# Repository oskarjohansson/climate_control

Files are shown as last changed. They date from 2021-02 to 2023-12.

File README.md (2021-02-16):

# Boot Climate Control
> Created by Benjamin Lundgren & Oskar Johansson

Based on [Ski boots hearing system](https://hackaday.io/project/163132-ski-boots-heating-system). 

## Goals 
> The goal of the Boot Climate Control (BCC)
```
- Never ever freeze in the boots
- Warm for ~8h
```

## Directories 
```
climate_control
├── document        # Generic document folder
│   ├── datasheet   # Datasheet for hardware components  
├── hardware        
│   ├── cad         # 3D models
│   │   └── stl     # 3D print files
│   ├── pcb         # Schematic, layout and production files
│   │   └── gerber  # Production files
│   │   └── library # Library for project
├── img             
└── software        # Firmware files
```

## Usage
> Description about how to use the BCC 

## License
> This template is created with MIT license.
>
> ](http://badges.mit-license.org)

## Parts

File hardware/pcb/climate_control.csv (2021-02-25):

Id | Designator | Package | Quantity | Designation | Supplier and ref
1 | J1 | JST_XH_B4B-XH-A_1x04_P2.50mm_Vertical | 1 | Switch |  | CASE
2 | U3 | TQFP-32_7x7mm_P0.8mm | 1 | ATmega328PB-AU |  | Benjamin
3 | C1,C4,C7,C8,C10 | C_0603_1608Metric | 5 | 10uF | C344022 | LCSC
4 | U1 | SOP8-EPAD | 1 | TP4056 | C725790 | LCSC
5 | U2 | SOP8-EPAD | 1 | XB8089A | C669690 | LCSC
6 | U4 | Texas_S-PVSON-N10_ThermalVias | 1 | TPS61230DRC | C139626 | LCSC
7 | D1 | D_0603_1608Metric | 1 | CHRG | C84269 | LCSC
8 | Q2 | SOT-23 | 1 | NTR3C21NZ | C344010 | LCSC
9 | J2 | JST_XH_B2B-XH-A_1x02_P2.50mm_Vertical | 1 | BatteryIn
10 | J4 | JST_XH_B2B-XH-A_1x02_P2.50mm_Vertical | 1 | HeatElement
11 | R1,R4 | R_0402_1005Metric | 2 | x
12 | R2,R14 | R_0402_1005Metric | 2 | 10k
13 | R9,R13 | R_0402_1005Metric | 2 | 5.1k
14 | R11 | R_0402_1005Metric | 1 | 2.4k
15 | R12 | R_0402_1005Metric | 1 | 100R
16 | R15,R3 | R_0402_1005Metric | 2 | 100k
17 | R17,R18 | R_0402_1005Metric | 2 | R_Small
18 | C3,C6,C11 | C_0402_1005Metric | 3 | 100nF
19 | C5 | C_0402_1005Metric | 1 | 1uF
20 | C9 | C_0402_1005Metric | 1 | 18nF
21 | J3 | HRO_TYPE-C-31-M-12 | 1 | USB_C | C165948 | LCSC
22 | J5 | PinHeader_2x03_P2.54mm_Vertical | 1 | ICSP
23 | L1 | Inductor_0530 | 1 | 1uH | C169353 | LCSC
24 | R5 | R_0402_1005Metric | 1 | 30k

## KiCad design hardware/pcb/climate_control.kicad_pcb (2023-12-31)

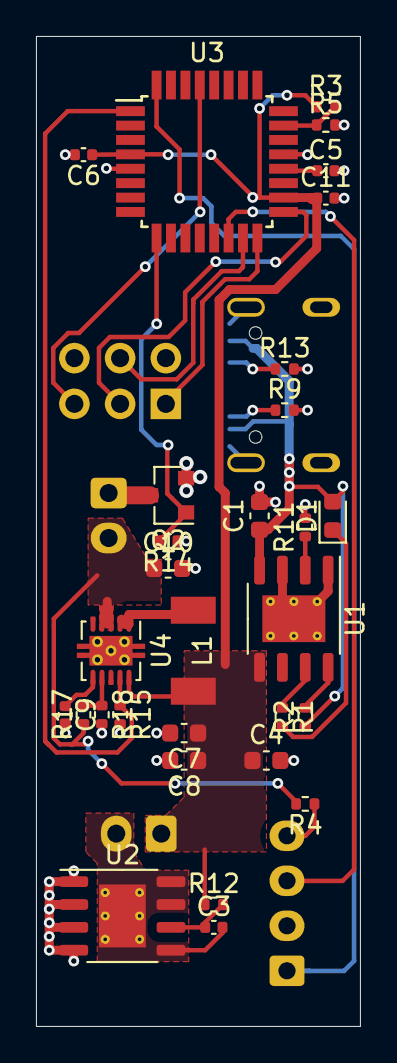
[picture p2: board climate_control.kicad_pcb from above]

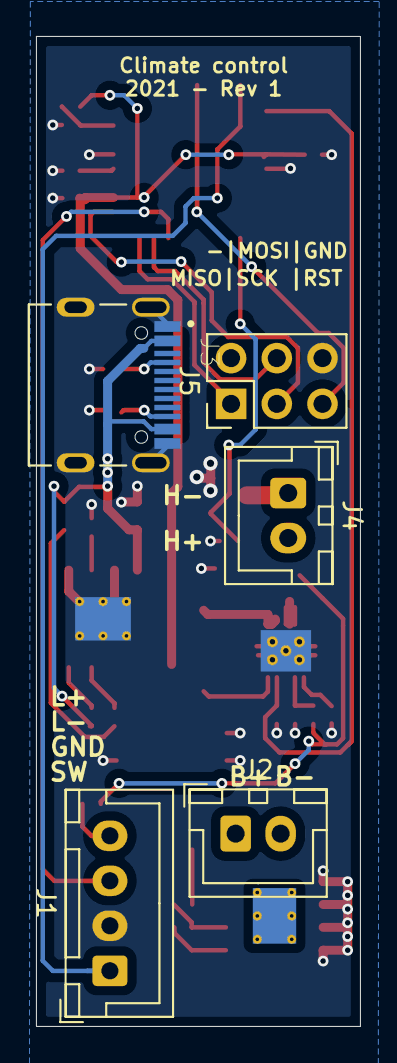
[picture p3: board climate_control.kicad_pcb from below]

Board: 2 copper layers, 18.0 x 55.0 mm, 35 parts (5 on the bottom side), 27 nets.

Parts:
C1, C4, C7, C8, C10: 10uF; C_0603_1608Metric
C3, C6, C11: 100nF; C_0402_1005Metric
C5: 1uF; C_0402_1005Metric
C9: 18nF; C_0402_1005Metric
D1: CHRG; D_0603_1608Metric
J1: Switch; JST_XH_B4B-XH-A_1x04_P2.50mm_Vertical
J2: BatteryIn; JST_XH_B2B-XH-A_1x02_P2.50mm_Vertical
J3: USB_C; HRO_TYPE-C-31-M-12
J4: HeatElement; JST_XH_B2B-XH-A_1x02_P2.50mm_Vertical
J5: ICSP; PinHeader_2x03_P2.54mm_Vertical
L1: 1uH; Inductor_0530
Q2: NTR3C21NZ; SOT-23
R1, R4: x; R_0402_1005Metric
R2, R14: 10k; R_0402_1005Metric
R3, R15: 100k; R_0402_1005Metric
R5: 30k; R_0402_1005Metric
R9, R13: 5.1k; R_0402_1005Metric
R11: 2.4k; R_0402_1005Metric
R12: 100R; R_0402_1005Metric
R17, R18: R_Small; R_0402_1005Metric
U1: TP4056; SOP8-EPAD
U2: XB8089A; SOP8-EPAD
U3: ATmega328PB-AU; TQFP-32_7x7mm_P0.8mm
U4: TPS61230DRC; Texas_S-PVSON-N10_ThermalVias

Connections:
+5V: C1.1, D1.2, J3.A4B9, J3.B4A9, R2.1, U1.4
+BATT: C4.1, C6.1, C7.1, C8.1, C11.1, J2.1, L1.1, R3.1, R12.1, U1.5, U3.4, U3.18, U4.10
+VSW: C10.1, J4.2, R4.2, R17.1, U4.3, U4.4
-BATT: C3.2, J2.2, U2.5, U2.7, U2.8, U2.9
BAT: R3.2, R5.1, U3.23
BOOST_EN: R15.1, U3.1, U4.9
GND: C1.2, C4.2, C5.2, C6.2, C7.2, C8.2, C9.2, C10.2, C11.2, J1.2, J3.A1B12, J3.B1A12, J3.S1, J5.6, Q2.2, R5.2, R9.2, R11.2, R13.2, R14.1, R15.2, R18.2, U1.1, U1.3, U1.9, U2.1, U2.2, U2.3, U2.4, U3.5, U3.21, U4.11
HEATER_PWM: Q2.1, R14.2, U3.9
LED: J1.3, U3.14
MISO: J5.1, U3.16
MOSI: J5.4, U3.15
unnamed: C3.1, R12.2, U2.6
unnamed: C5.1, U3.20
unnamed: C9.1, U4.6
unnamed: D1.1, R1.2
unnamed: J1.4, R4.1
unnamed: J3.A5, R13.1
unnamed: J3.B5, R9.1
unnamed: J4.1, Q2.3
unnamed: L1.2, U4.1, U4.2
unnamed: R1.1, U1.7
unnamed: R2.2, U1.8
unnamed: R11.1, U1.2
unnamed: R17.2, R18.1, U4.7
SCK: J5.3, U3.17
SWITCH: J1.1, U3.32
~RST: J5.5, U3.29

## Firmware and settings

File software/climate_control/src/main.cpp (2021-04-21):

#include <Arduino.h>
#include <utils.h>
#include <button.h>
#include <heater.h>
#include <constants.h>

/*
DONE: Verify debouncing and click pattern detection
DONE: Verify Led output
DONE: Verify boost circuit working

TODO: Verify getSoc()
TODO: Verify sleep function (measure current draw)
TODO: Verify heater function
*/
Button switchButton(switchPin);
Heater heater(heaterPwmPin, boostEnablePin, ledPin);

// For battery soc led
uint8_t queueIndex = 0;
unsigned long socLastCycle = 5000;

void setup()
{
  Serial.begin(9600);
  //Serial.println("Hello World!");
  pinMode(ledPin,INPUT);
  flash(ledPin, 3, 250, 250);
  pinMode(boostEnablePin,OUTPUT);
  digitalWrite(boostEnablePin,HIGH);
  analogReference(INTERNAL1V1);
}

void loop()
{
  unsigned long now = millis();
  // Read battery status
  uint8_t Soc = getSoc();
  if (Soc)
  {
    // Check if button is pressed
    int click = switchButton.poll();
    switch (click)
    {
      case clickTypes::singleClick:
        //Serial.println("Single click detected!");
        socLastCycle = now + socLedCycle;
        if (heater.isActive())
          heater.increment();
        break;
      case clickTypes::doubleClick:
        //Serial.println("Double click detected!");
        socLastCycle = now + socLedCycle;
        if (heater.isActive())
          heater.decrement();
        break;
      case clickTypes::tripleClick:
      { // Get battery status
        //Serial.println("Triple click detected!");
        socLastCycle = now + socLedCycle;
        //heater.pause();
        //delay(10);
        //uint8_t soc = getSoc();
        //flash(ledPin, soc+1, 500, 250);
        //heater.resume();
        break;
      }
      case clickTypes::longClick:
        if (heater.isActive())
        {
          //Serial.println("Turning off heater!");
          heater.off();
        }
        else
        {
          //Serial.println("Turning on heater!");
          heater.on();
        }
        break;
      
    }
    // If neither heater active nor switchbutton active
    if (!(switchButton.isActive() || heater.isActive()))
    {
      //Serial.println("Inactive, going to sleep!");
      delay(25);
      goToSleep();
    }

    // Blink battery level led
    else if((now>socLastCycle))
    {
      Serial.print(Soc); Serial.print(" "); Serial.println(analogRead(batSensePin));
      uint8_t ledMode = socLedPattern[Soc-1][queueIndex];
      if(ledMode) 
      {        
        pinMode(ledPin, OUTPUT);
        digitalWrite(ledPin, LOW);
      }
      else 
      {
        pinMode(ledPin, INPUT);
      }

      queueIndex = (queueIndex + 1) % (sizeof(socLedPattern[Soc])+1);
      // If queueIndex is zero, wait another 5s
      if(queueIndex<1){
        socLastCycle = now + socLedCycle;
        pinMode(ledPin, OUTPUT);
        digitalWrite(ledPin, LOW);
      }
      else 
      {
        socLastCycle = now + socLedTimestep;
      }
    }





  }
  else
  {
    delay(25);
    //disable heater
    heater.off();
    //disable led
    pinMode(ledPin, INPUT);
    // Sleep
    goToSleep();
  }
}

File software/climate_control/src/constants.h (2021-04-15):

#ifndef __CONSTANTS__
#define __CONSTANTS__
const int switchPin = 2;       //PD2
const int switchInterrupt = 0; //PD2

const int boostEnablePin = 3; //PD3
const int boostMosPin = 4;    //PD4
const int heaterPwmPin = 5;   //PD5
const int usbDetectPin = 16;  //PC2
const int ledPin = 10;        //PB2
const int batSensePin = A0;

const int debouncingTime = 50;
const int groupClickInterval = 300; 
const int longClickDuration = 1000;
const int inactiveTime = 5000;

const unsigned long socLedTimestep = 400;   // Timestep
const unsigned long socLedCycle = 5000;     // How often the soc should cycle
const uint8_t socLedPattern[3][5] = {{0,1,1,1,1},{0,1,0,1,1},{0,1,0,1,0}}; // The pattern for the three battery levels

const float voltPerInc = 0.0062; // Magic number ;-) 1.1 * ((100 + 30) / 30) / 1024; // internal_ref * voltage_division⁽⁻¹⁾ / resolution
//const int underVoltThreshold = 447; //2.8 / voltPerInc;
const int underVoltThreshold = 635; //2.8 / voltPerInc;

const int batteryReads = 10;
const int batSocVoltageLevels = 3;
//const unsigned int batSocVoltage[] = {underVoltThreshold, 535, 624};
const int batSocVoltage[] = {underVoltThreshold, 760, 830};
                                      /*{(unsigned int)(3.48 / voltPerInc),  // ~20%
                                      (unsigned int)(3.60 / voltPerInc),  // ~40%
                                      (unsigned int)(3.71 / voltPerInc),  // ~60%
                                      (unsigned int)(3.90 / voltPerInc),  // ~80%
                                      (unsigned int)(4.15 / voltPerInc)}; // ~ 95%*/

enum clickTypes {
    noClick,
    singleClick,
    doubleClick,
    tripleClick,
    longClick
};

const int heaterStartLevel = 1;
const int heaterNumberOfLevels = 2;
const int heaterLevels[] = {100, 175, 255};

#endif

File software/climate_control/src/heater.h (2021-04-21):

#include <constants.h>

class Heater
{
    uint8_t currentLevel;
    bool active;


    uint8_t pwmPin;
    uint8_t enablePin;
    uint8_t ledPin;

    public:
    Heater(uint8_t pwmPin, uint8_t enablePin, uint8_t ledPin)
    {
        this->pwmPin = pwmPin;
        this->enablePin = enablePin;
        this->ledPin = ledPin;
        digitalWrite(pwmPin, LOW);
        digitalWrite(enablePin, LOW);

        currentLevel = 0;
        active = false;
    }
    
    void pause()
    {
        digitalWrite(pwmPin, LOW);
        digitalWrite(enablePin, LOW);
        active = false;
    }
    void resume()
    {
        analogWrite(pwmPin, heaterLevels[currentLevel]);
        digitalWrite(enablePin, HIGH);
        active = true;
    }
    void off()
    {
        digitalWrite(pwmPin, LOW);
        digitalWrite(enablePin, LOW);
        active = false;
        currentLevel = 0;
        pinMode(ledPin, INPUT);
    }
    void on()
    {
        currentLevel = heaterStartLevel;
        digitalWrite(enablePin, HIGH);
        analogWrite(pwmPin, heaterLevels[currentLevel]);
        pinMode(ledPin, OUTPUT);
        digitalWrite(ledPin, LOW);
        active = true;
    }

    void increment()
    {
        if (currentLevel < (heaterNumberOfLevels))
            currentLevel ++;
        active = true;
        digitalWrite(enablePin, HIGH);
        analogWrite(pwmPin, heaterLevels[currentLevel]);
        flash(ledPin, currentLevel+1, 200, 200);
        pinMode(ledPin, OUTPUT);
        digitalWrite(ledPin, LOW);
    }
    void decrement()
    {
        if (currentLevel > 0)
            currentLevel --;
        active = true;
        digitalWrite(enablePin, HIGH);
        analogWrite(pwmPin, heaterLevels[currentLevel]);
        flash(ledPin, currentLevel+1, 200, 200);
        pinMode(ledPin, OUTPUT);
        digitalWrite(ledPin, LOW);
    }
    bool isActive()
    {
        return active;
    }
};

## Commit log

2021-02-16 Added components to schematic and library
    Added Battery protection
    Added Boost charger
    Added USB Connector
    Added Boost module
2021-02-16 Correct title on battery charger.
    Wrote boost before, when it is a buck charger. Now corrected.
    [climate_control.sch]
2021-02-17 Added image of Arduino Pro Mini
2021-02-17 Added datasheet for BMS
2021-02-17 Added MCU and better control.
    MCU with all connection is added.
    Output to heater now has a mosfet to PWM to.
    LED Switch has a connection with mosfet to control LED.
    LED Switch has a LP filter for debounce purpose.
    [climate_control.sch]
2021-02-18 All components added to schematic and pcb.
    Footprints for all parts is done and only routing is left.
    [climate_control.sch]
2021-02-18 Removed resistor on TP4056.
    Updated on PCB the routing.
    [climate_control.kicad_pcb, climate_control.sch]
2021-02-18 First routing complete.
    The first routing is done, now it must be improved!
    [climate_control.kicad_pcb]
2021-02-18 Added comments on LED/Switch circuitry
    [climate_control.sch]
2021-02-20 Removed unnececary components
    [climate_control.kicad_pcb, climate_control.sch]
2021-02-20 Second routing process done
    [climate_control.kicad_pcb]
2021-02-20 Routing complete and added some silkscreen.
    [climate_control.kicad_pcb, climate_control.sch]
2021-02-22 Added datasheet for all components.
    Added datasheet for all components except passives and connectors.
2021-02-22 Added battery divider to MCU.
    A voltage divider from the battery is now connected to the MCU.
    The divider is designed to work with the internal voltage reference (1V1).
    With the resistor values, a battery voltage of 5 V will be 1.15 at MCU.
    [climate_control.kicad_pcb, climate_control.sch]
2021-02-23 Removed crystal.
    The ATMega does not need an external crystal. Now removed.
    [climate_control.kicad_pcb, climate_control.sch]
2021-02-23 Export .stp from PCB.
2021-02-25 Final first revision ordered.
    [climate_control-B_Cu.gbr, climate_control-B_Mask.gbr, climate_control-B_Paste.gbr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]
2021-03-16 Changed platformIo settings
    Upload settings for using atmel ice in ubuntu.
    Board frequency and fuses to get correct timing.
2021-03-16 Software verification
    Tested
    - enabling of boost converter
    - toggling led
    - reading button
    - debouncing and click pattern detection
2021-04-12 Fixed sleep and changing power level. Still too high sleep current.
    [constants.h, heater.h, main.cpp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]
2021-04-13 Fixed sleeping issue and led indication for heater
    [heater.h, utils.h]
2021-04-14 Added SOC led blinks.
    The LED will now blink according to the return of getSoc.
    There are three levels,
    0% - 40%, 40% - 70% and 70% - 100%.
    One blink is lowest and three is full.
2021-04-21 Added fuse settings for ATMega328PB
2021-04-21 Fixed deadlock when sleeping (Hopefully :) )
    [heater.h, main.cpp, utils.h]
2023-12-31 Convert to Kicad 7
    [climate_control.kicad_pcb, climate_control.kicad_sch, climate_control.sch]
